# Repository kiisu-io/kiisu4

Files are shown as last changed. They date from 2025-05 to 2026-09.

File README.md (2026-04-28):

# Kiisu V4 docs, schematics and resources

## Kiisu V4b

[User Manual and Quick Start guide](https://github.com/kiisu-io/kiisu4/blob/main/kiisu%20v4b%20manual%20and%20quick%20start.pdf)

[Schematics](https://github.com/kiisu-io/kiisu4/blob/main/kiisu%20v4b%20schematics.pdf)

[STL file of board](https://github.com/kiisu-io/kiisu4/blob/main/kiisu%20v4b%20model.stl)

## Kiisu V4a

[User Manual for Kiisu v4a](https://github.com/kiisu-io/kiisu4/blob/main/previous/kiisu%20v4a%20manual.pdf)

[Schematics for Kiisu v4a](https://github.com/kiisu-io/kiisu4/blob/main/previous/kiisu%20v4a%20schematics.pdf)

## Check other resources:
- [Kiisu.io website](https://kiisu.io).
- [Buy Kiisu here](https://store.rainwalker.ee/products/kiisu-v4).
- [Our Discord Community](https://discord.gg/kiisu) can help with your questions.
- [Flipper Zero docs](https://docs.flipper.net/) to know more about Bluetooth, RFID, NFC, IR and other technologies and how to interact with it using compatible firmware on Kiisu board.

- [Aux MCU firmware to support Flipper Zero firmwares](https://github.com/kiisu-io/kiisu4-companion-fw).
- [Fork of Flipper Zero firmware for Kiisu](https://github.com/kiisu-io/kiisu-firmware).
- [Twoelw's GitHub](https://github.com/twoelw) with useful apps and firmware for Kiisu.

- [Cases and stuff for 3D printing on Printables](https://www.printables.com/@planmarks/collections/2364779).
- [Cases and stuff for 3D printing on Makerworld](https://makerworld.com/ru/collections/6517412-kiisu-devboard).

## See also

- [KIISU SMOL](https://github.com/kiisu-io/kiisu-smol) — hardware design files for our modular networking development board (currently on [Indiegogo](https://www.indiegogo.com/projects/rainwalker/kiisu-smol---networking-development-board)).

## License

Hardware design files (schematics, 3D models) are released under the [CERN Open Hardware Licence Version 2 — Strongly Reciprocal (CERN-OHL-S v2)](LICENSE).

Documentation, manuals, and this README are released under the [Creative Commons Attribution-ShareAlike 4.0 International (CC BY-SA 4.0)](LICENSE-DOCS).

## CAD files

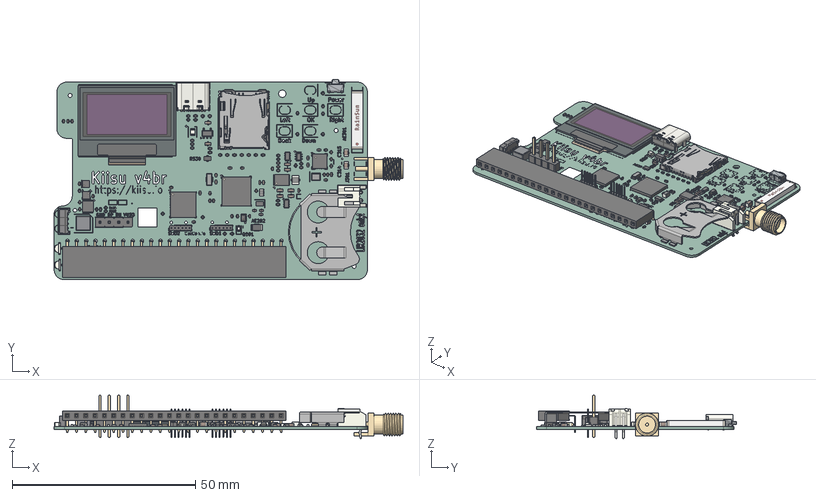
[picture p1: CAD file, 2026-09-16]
kiisu v4br model.step
95.3 x 54.8 x 11.9 mm
C_0402_1005Metric x 73
R_0402_1005Metric x 77
C_0603_1608Metric x 10
LED_0805_2012Metric
BatteryHolder_Keystone_3034_1x20mm
QFN-32-1EP_5x5mm_Pitch0.5mm
C_0805_2012Metric x 3
QFN-48-1EP_7x7mm_Pitch0.5mm
Crystal_SMD_2520-4Pin_2.5x2.0mm
User Library-0_96__OLED v7 v1
User Library-0_96__OLED v7 v002
User Library-0_96__OLED v7 v003
User Library-0_96__OLED v7 v004
D_SOD_523 x 4
SOT-323_SC-70
SOT-363_SC-70-6 x 5
MicroCrystal_CC8V_T1A
SOT-23-3
Bosch_LGA_8_3x3mm_P08mm_ClockwisePinNumbering
DFN-6-1EP_2x2mm_Pitch0.5mm
Scale (Solid)
R_1206_3216Metric
HeimdallW
PinHeader_1x06_P100mm_Vertical x 2
R_0805_2012Metric x 2
L_1008_2520Metric
LGA_12_2x2mm_P05mm
QFN-16-1EP_3x3mm_P0.5mm_EP1.7x1.7mm
DFN-14-1EP_3x4mm_Pitch0.5mm
L_0402_1005Metric x 2
LED_XINGLIGHT_1204_3210Metric_SideView x 2
USB_C_Receptacle_16P_TopMnt_Horizontal_GCT_USB4105-xx-A
L_0805_2012Metric x 3
PinHeader_1x04_P254mm_Vertical
SOT-583-8 x 2
F6C42762-D111-4FB0-B9BB-3CBC5E40C018
QFN_68_1EP_8x8mm_P04mm_EP52x52mm
Texas_RGP0020H_VQFN-20-1EP_4x4mm_P0.5mm_EP2.4x2.4mm
Crystal_SMD_3215-2Pin_3.2x1.5mm
SOT-23-5
microSD_HC_Hirose_DM3AT-SF-PEJM5
L_Abracon_ASPI-0425
LED_0603_1608Metric
JST_S2B_PH_K
D_SOD-323
Crystal_SMD_3225-4Pin_3.2x2.5mm
Filter_Mini-Circuits_FV1206-5
SMA_Samtec_SMA-J-P-H-ST-EM1_EdgeMount
PinSocket_1x24_P2.54mm_Horizontal
kii89D0_silkscreen x 2
kii89D0_PCB

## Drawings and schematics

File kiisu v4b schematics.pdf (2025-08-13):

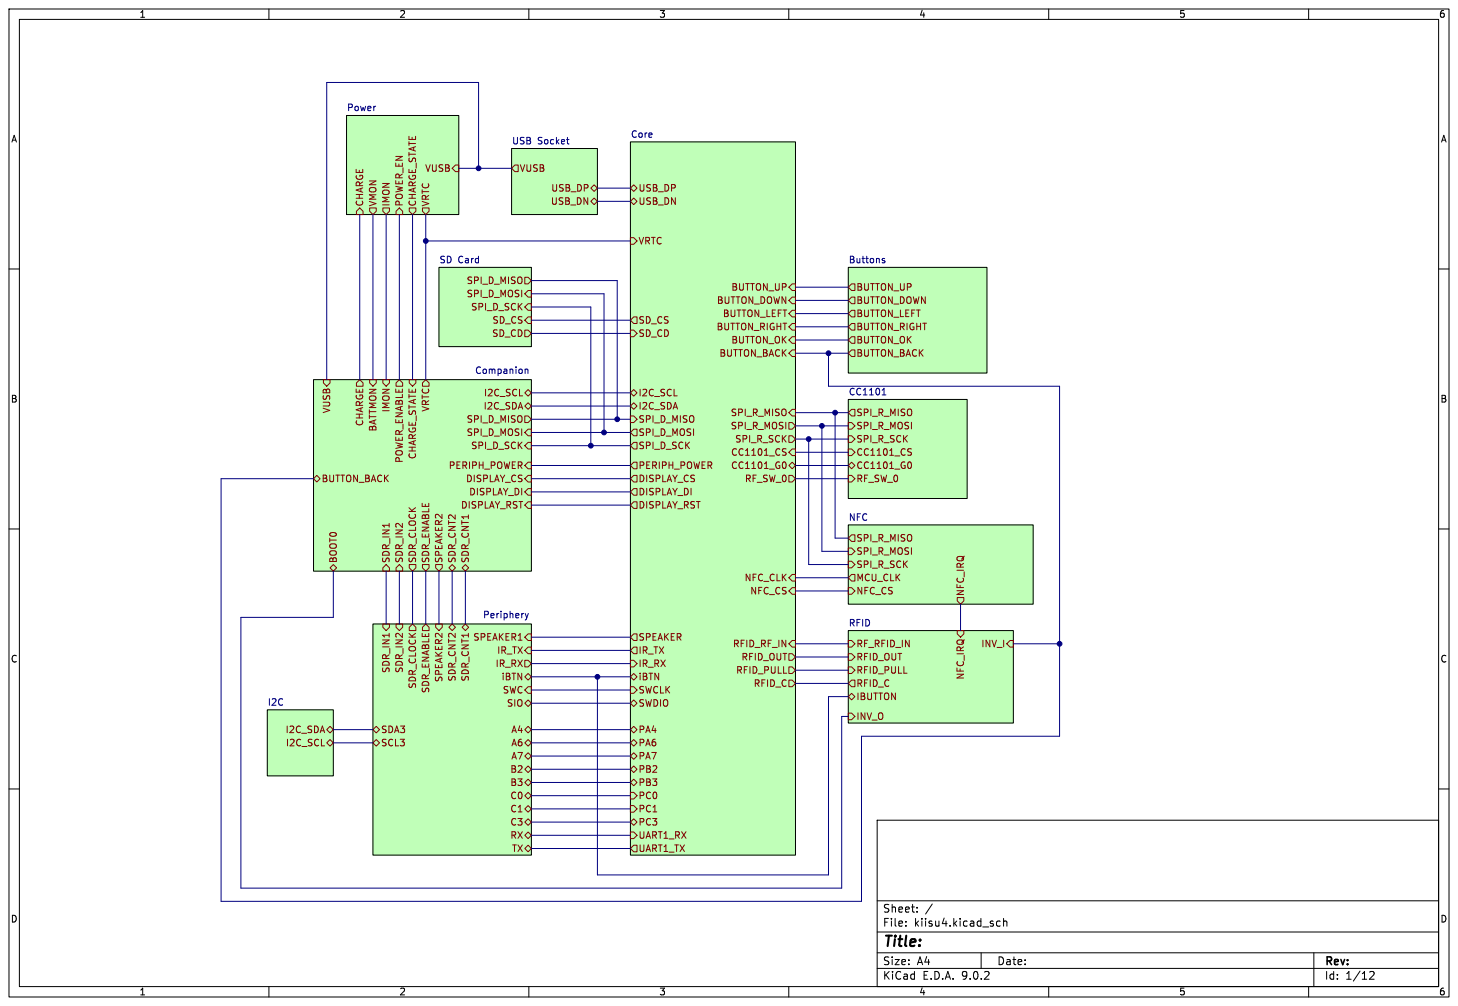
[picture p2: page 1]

VUSB CHARGE VMON IMON POWER_EN CHARGE_STATE VRTC

Id: 1/12 Title: File: kiisu4.kicad_sch Sheet: /

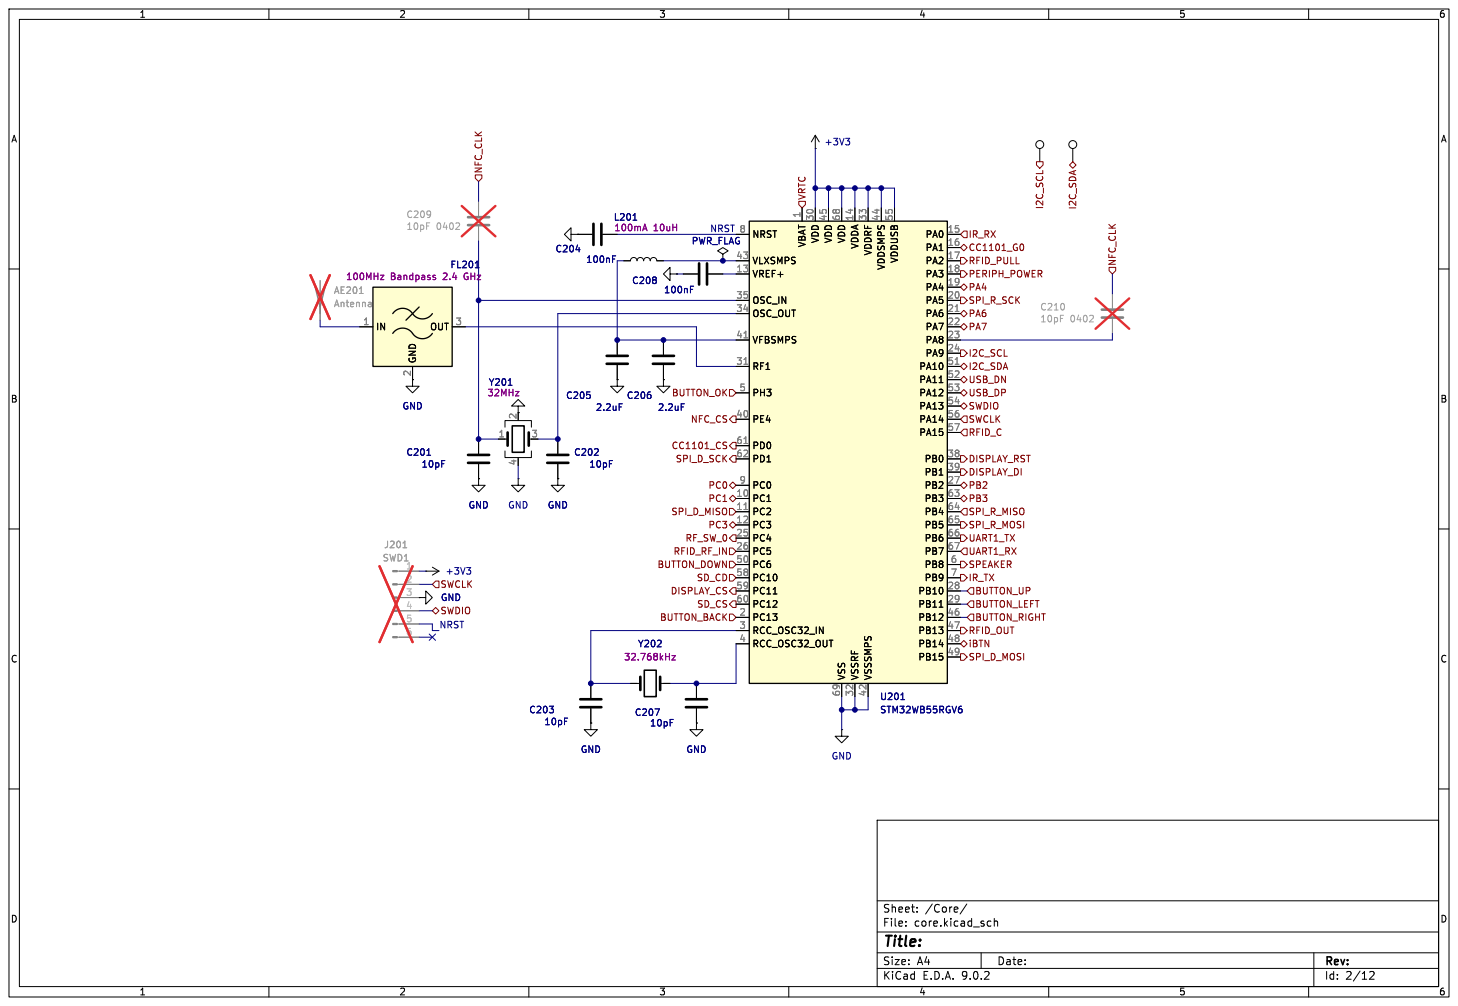
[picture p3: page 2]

Id: 2/12 Title: File: core.kicad_sch Sheet: /Core/ C201

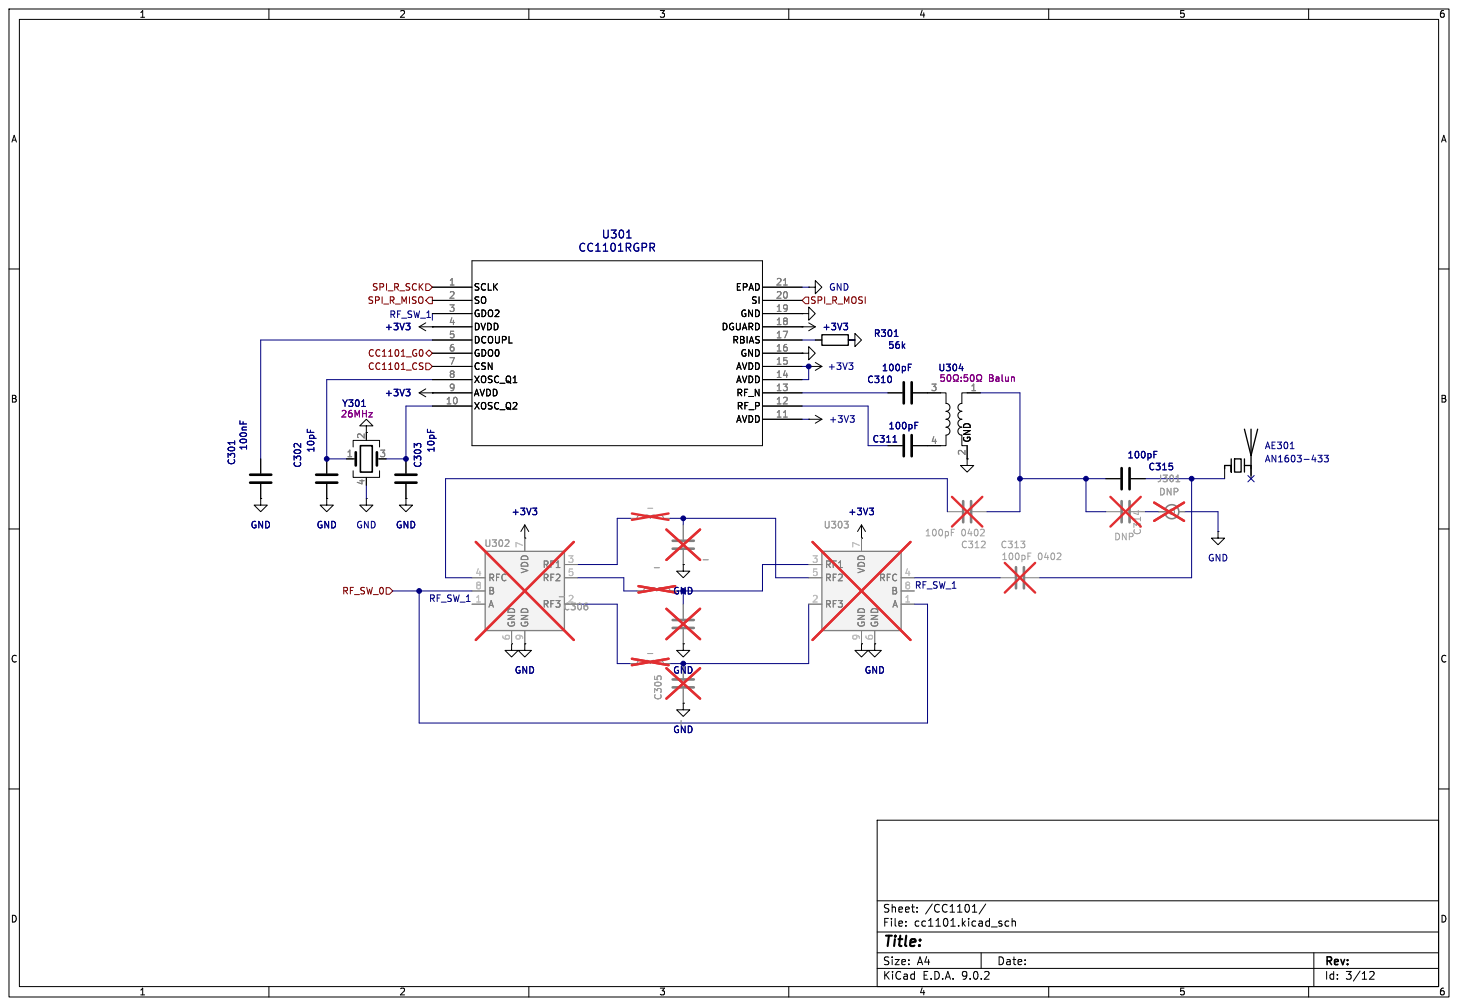
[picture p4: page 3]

Id: 3/12 Title: File: cc1101.kicad_sch Sheet: /CC1101/

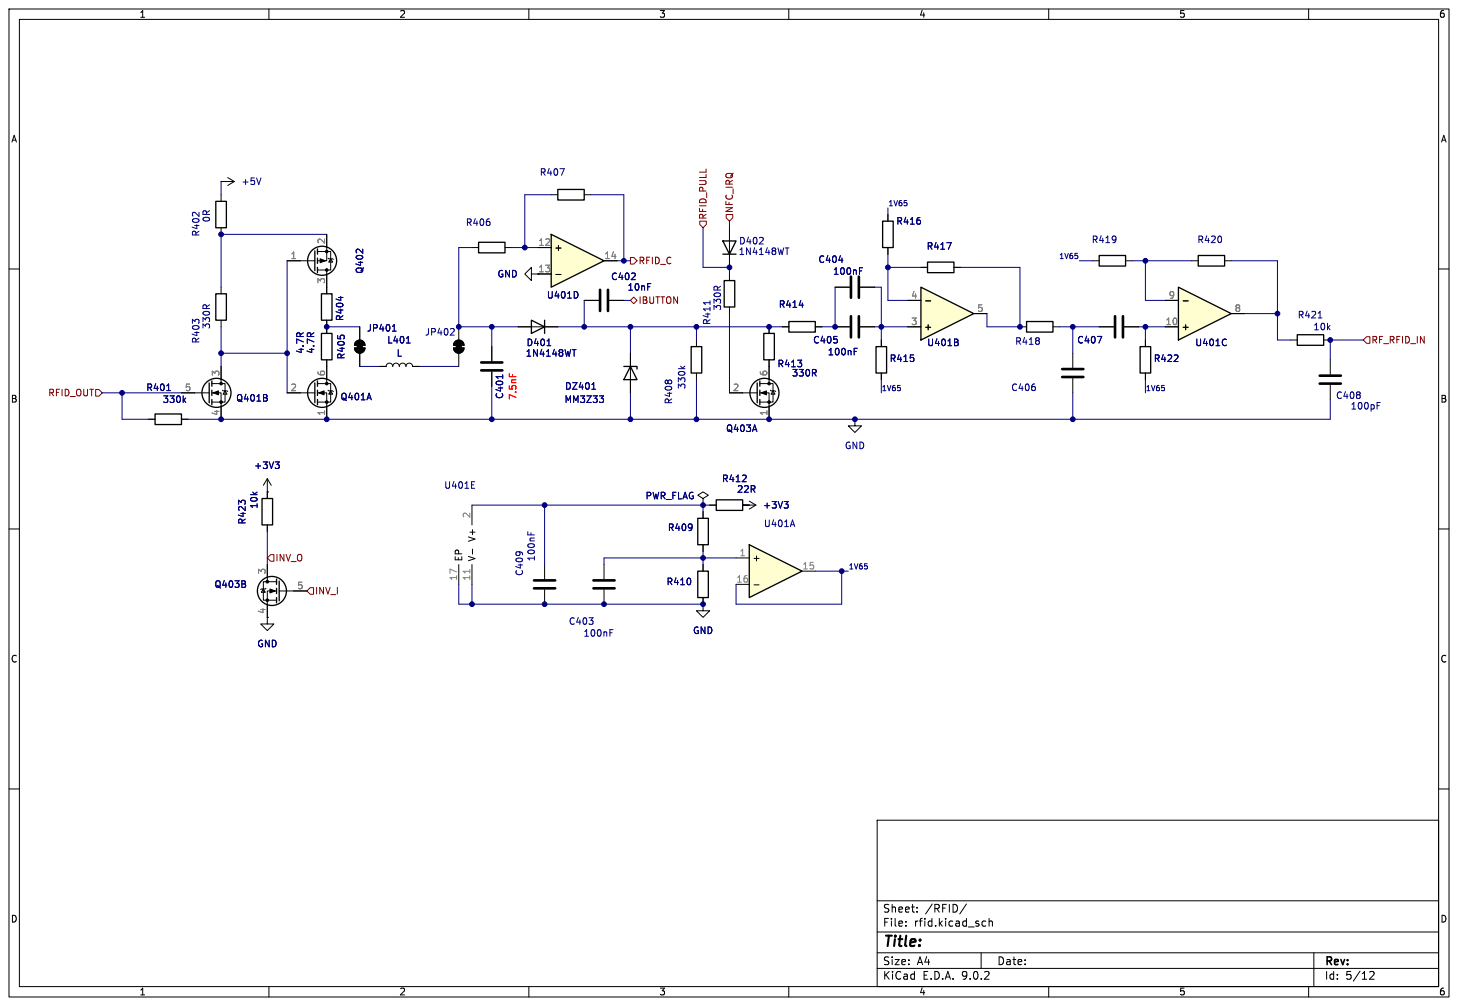
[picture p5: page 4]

Id: 5/12 Title: File: rfid.kicad_sch Sheet: /RFID/

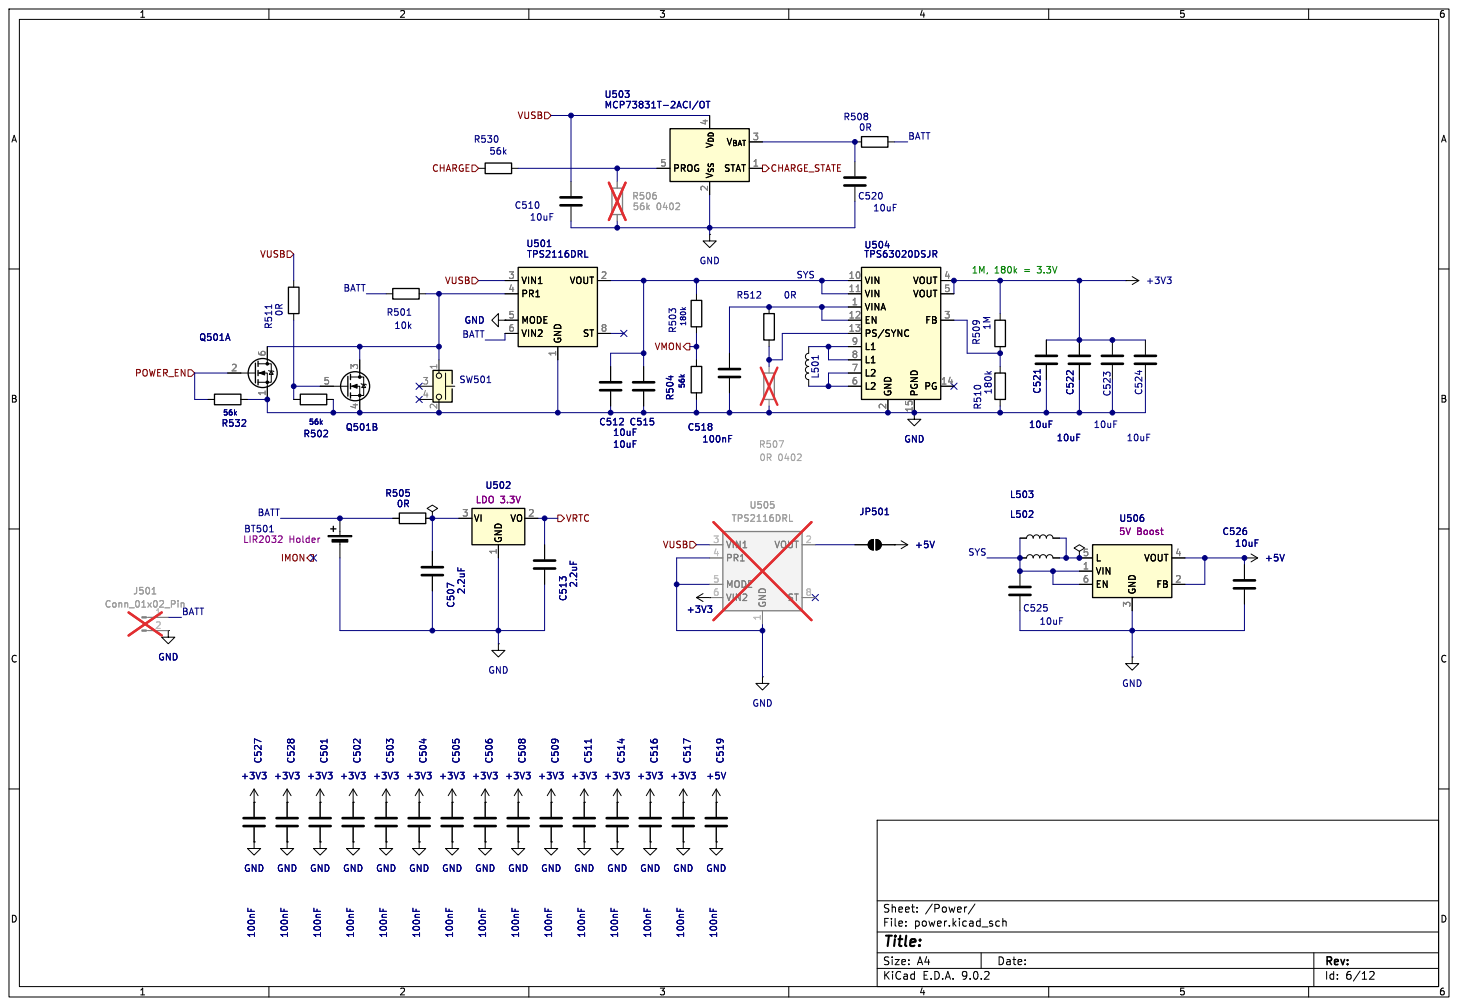
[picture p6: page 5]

1 VOUT 2 ST 8 +3V3 U501 TPS2116DRL VIN1 3 PR1 4 MODE 5 VIN2 6 GND

2 PGND 15 VOUT 4 VOUT 5 FB 3 PG 14 U504 TPS63020DSJR

2 PGND 15 VOUT 4 VOUT 5 FB 3 PG 14 U506

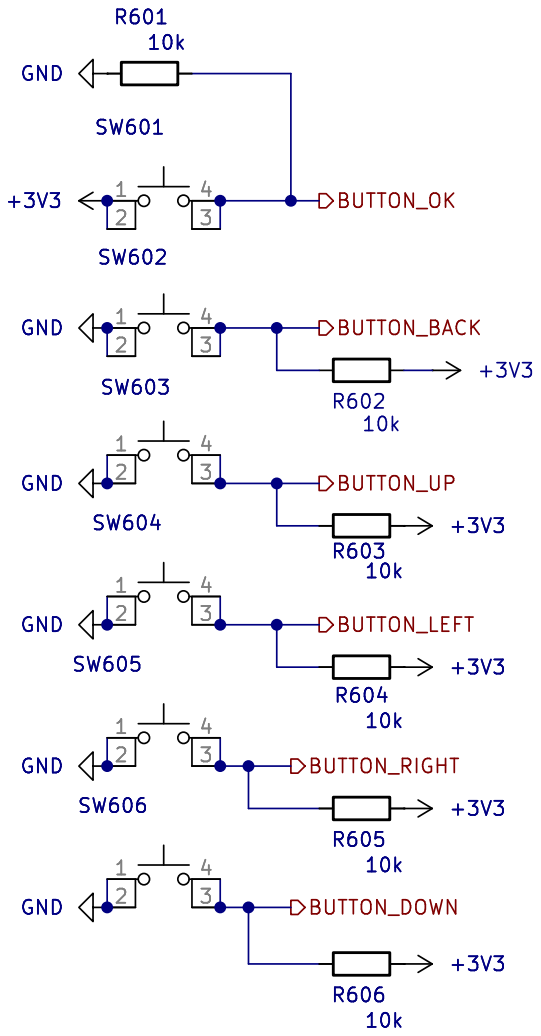
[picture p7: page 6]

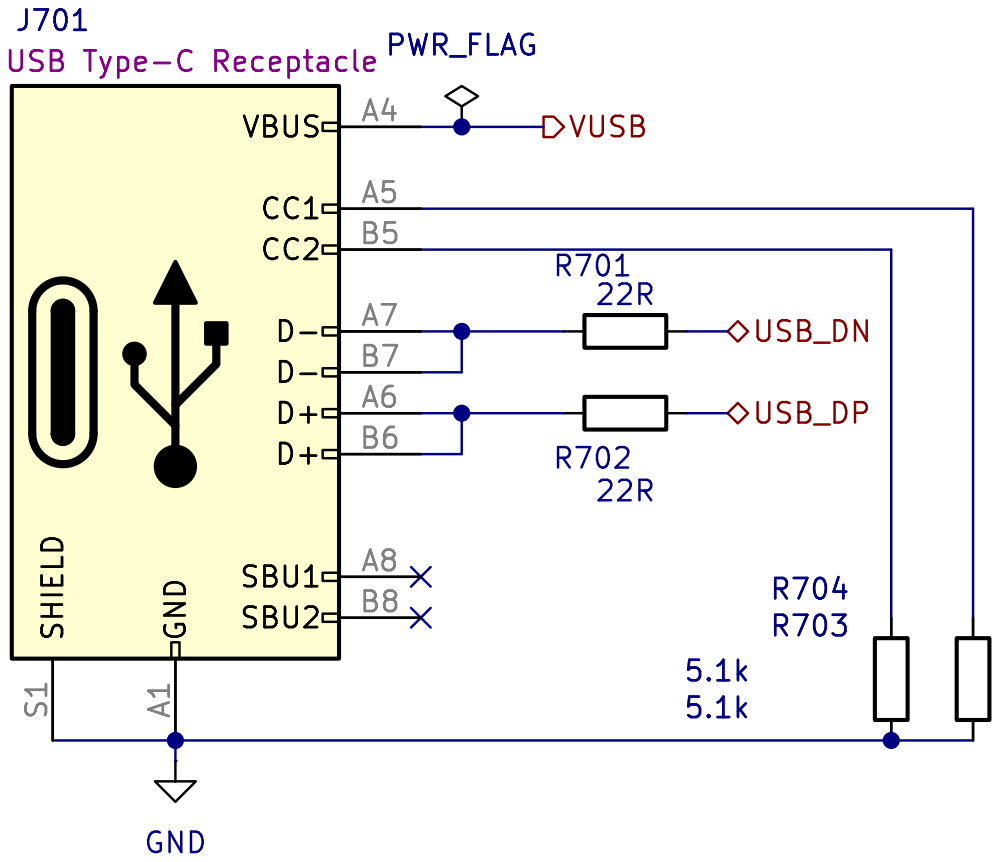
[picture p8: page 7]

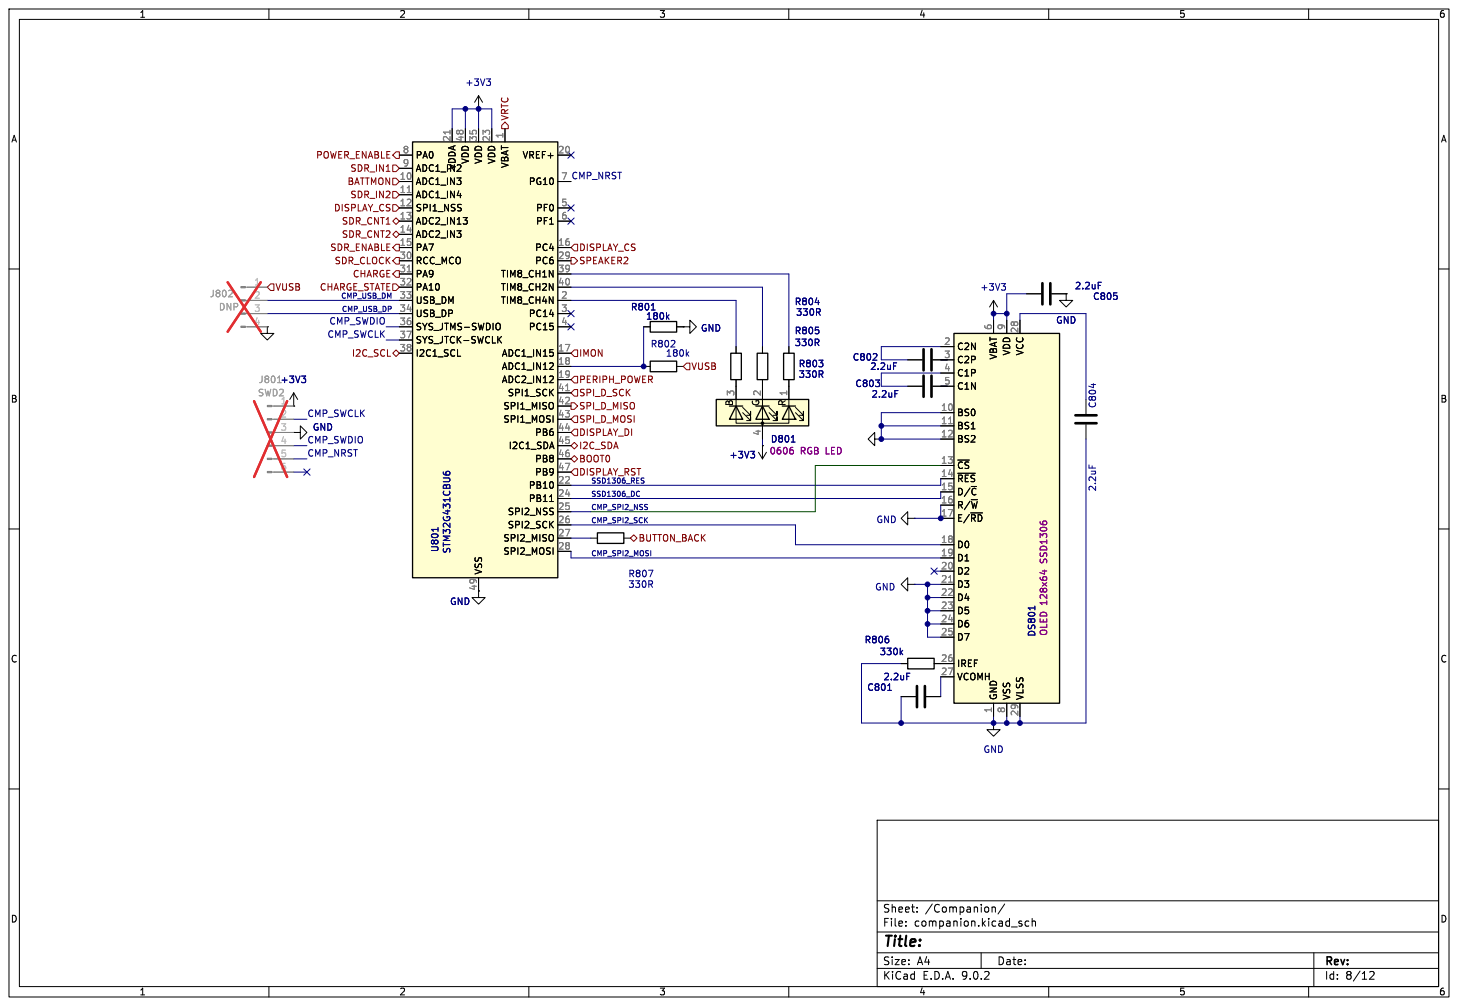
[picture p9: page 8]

Id: 8/12 Title: File: companion.kicad_sch Sheet: /Companion/

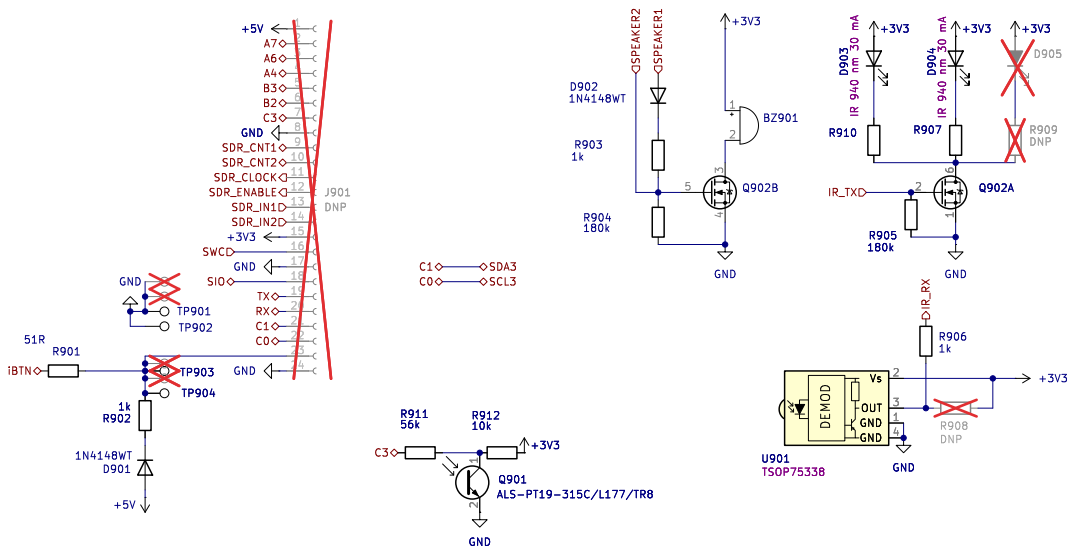
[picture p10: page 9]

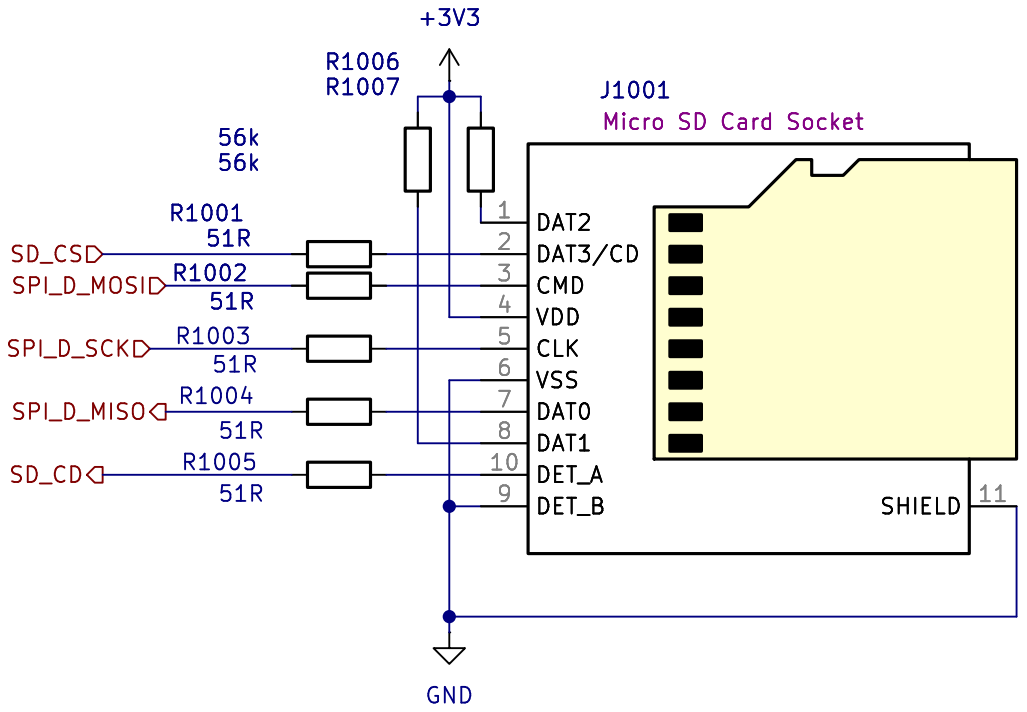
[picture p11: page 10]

J1001 Micro SD Card Socket SPI_D_SCK

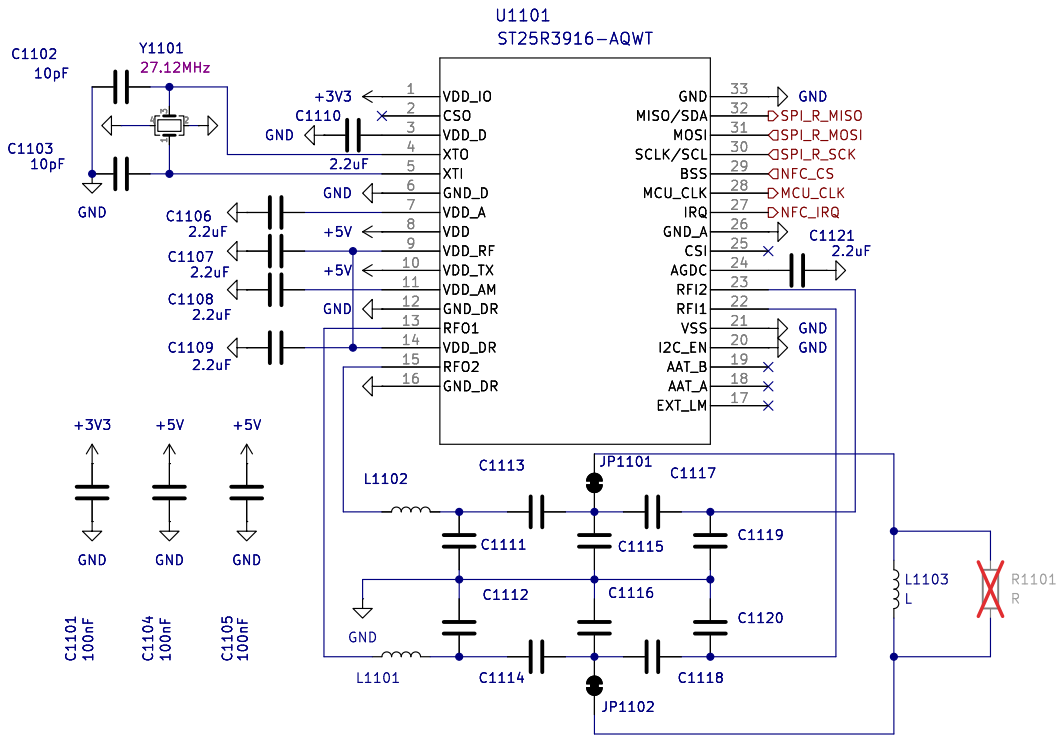
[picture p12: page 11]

Id: 11/12 Title: File: nfc.kicad_sch Sheet: /NFC/

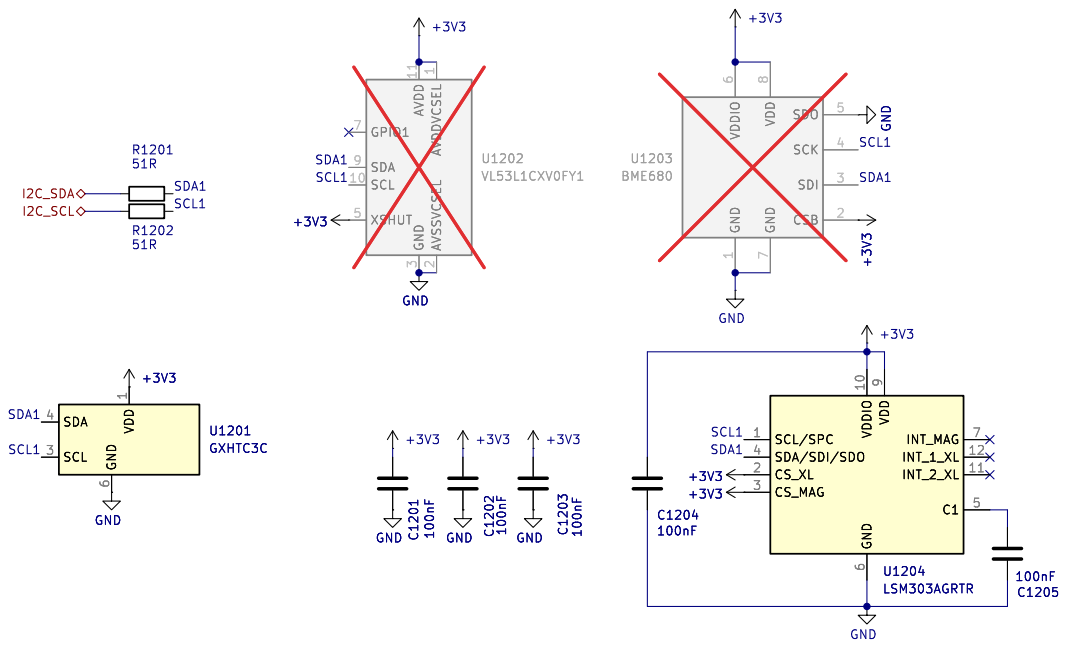
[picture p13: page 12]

1 U1202 VL53L1CXV0FY1 GPIO1 7 SDA 9 SCL 10 XSHUT 5 AVDD 11 GND

7 SDO 5 SCK 4 SDI 3 CSB 2 U1203 BME680 +3V3 GND

7 SDO 5 SCK 4 SDI 3 CSB 2 +3V3

2 GND C1203 100nF GND GND C1202 100nF GND C1201 100nF

Id: 12/12 Title: File: I2C.kicad_sch Sheet: /I2C/

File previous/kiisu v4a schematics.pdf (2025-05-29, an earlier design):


USB Socket VUSB CHARGE VMON IMON POWER_EN CHARGE_STATE VRTC

Id: 1/12 Title: File: kiisu4.kicad_sch Sheet: /


Id: 2/12 Title: File: core.kicad_sch Sheet: /Core/


Id: 3/12 Title: File: cc1101.kicad_sch Sheet: /CC1101/


Id: 5/12 Title: File: rfid.kicad_sch Sheet: /RFID/


2 PGND 15 VOUT 4 VOUT 5 FB 3 PG 14 U504 TPS63020DSJR

VIN 10 VIN 11 VINA 1 EN 12 PS/SYNC 13

2 PGND 15 VOUT 4 VOUT 5 FB 3 PG 14

1 VOUT 2 NC 7 ST 8 GND

1 VOUT 2 NC 7 ST 8 U505 VI TPS2116DRL 3 GND

Id: 6/12 Title: File: power.kicad_sch Sheet: /Power/




Id: 8/12 Title: File: companion.kicad_sch Sheet: /Companion/



J1001 Micro SD Card Socket SPI_D_SCK


Id: 11/12 Title: File: nfc.kicad_sch Sheet: /NFC/ C1114 GND


7 SDO 5 SCK 4 SDI 3 CSB 2 U1203 BME680 +3V3GND +3V3 C1202 100nF 0402 GPIO1 7 SDA 9 SCL 10 XSHUT 5 AVDD 11 GND

7 SDO 5 SCK 4 SDI 3 CSB 2 +3V3 GND

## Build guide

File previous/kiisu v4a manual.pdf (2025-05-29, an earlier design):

1

# Kiisu Development Board v4a

# User Manual

Rainwalker OU, 2025
Document version 1.0 from 1.04.2025 Find the latest version here: https://github.com/kiisu-io/kiisu4

2

## Cautions and warnings

1. This is a development board intended for experienced users; it is not a consumer product.
2. The development board can contain small and/or dangerous parts and must be kept away from children.
3. Use only LIR2032 batteries, never use CR2032 or another types on coin cell batteries.
4. Development board can emit radio frequency signals. Users are responsible for complying with local EMI regulations.

## Contents

6. Updating and debugging Main and Aux MCU with ST-Link or

## 1. Board overview

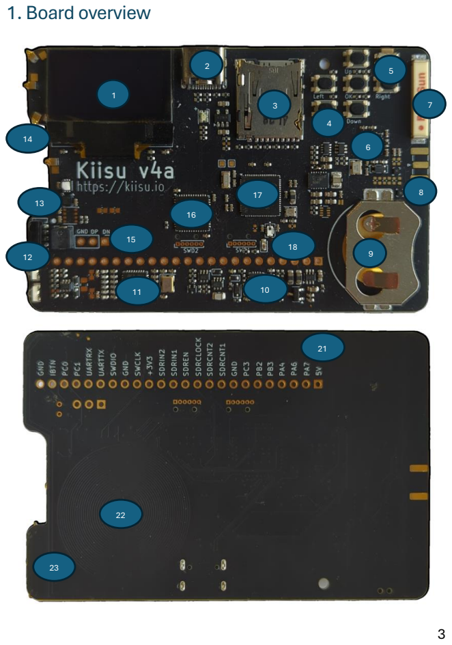
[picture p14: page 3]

4

1. OLED 128x64 screen, SSD1306 compatible in SPI mode.
2. USB Type C connected to Main MCU (17), supports charging of LIR2032 battery (9).
3. microSD Card slot.
4. Control buttons.
5. Power On button.
6. SubGhz transceiver CC1101.
7. Internal 433 MHz antenna for CC1101.
8. Place for SMA connector for external antenna.
9. LIR2032 battery connector. Do not use another type of coin cell batteries!
10. RFID reader and emulator with built-in antenna (23).
11. NFC reader and emulator ST25R3916 with built-in antenna (23).
12. Infrared receiver and transmitter.
13.Digital accelerometer and compass LSM303AGR. Temperature and humidity sensor GXHTC3C.
Gas sensor measuring relative humidity, barometric pressure, ambient temperature and gas (VOC) BME680 can be installed by user.
Digital ranger VL53xxx can be installed by user.
14. iButton memory reader and emulator pins
15.USB header connected to Aux MCU (16).
16. Aux MCU STM32G431CBU6 up to 170 MHz 17.Main MCU STM32WB55RGV6 up to 80 MHz
18. Ambient light sensor
21. GPIO pins.

5

## 2. Schematics and resources

Board schematics, latest version of this manual can be found here: https://github.com/kiisu-io/kiisu4
Aux MCU demonstration firmware can be found here: https://github.com/kiisu-io/kiisu4-companion-fw
This firmware allows to run and develop any Flipper Zero firmware with some limitations. (Note: Rainwalker OU and Kiisu board are NOT affiliated with Flipper Zero Devices Inc or team)
Fork of official Flipper Zero Firmware can be found here: https://github.com/kiisu-io/kiisu-firmware
This fork can also be run on Flipper Zero.

## 3. Limitations of compatibility

Despite this development, the board can run almost any firmware for the Flipper Zero device, there are some limitations:
1. The board doesn’t contain Flipper Zero secret keys, so official firmware may not support some SubGhz protocols and U2F.
2. The performance of board antennas can differ.
3. Some parts of the schematic are different, so features like battery status depend on Aux MCU firmware.
4. Once again, this is development board, not final end user device.

6

## 4. Powering on

Board can be powered from USB (2), from Li-Ion battery LIR2032 (9) and external Li-Ion battery.
In the case of USB, the board will turn on automatically and will remain powered until there is USB voltage.
In case of LIR2032, users should press Power On button (5). Board power than controlled by Aux MCU.

## 5. Updating firmware for Main MCU over USB

1. Disconnect USB and remove battery.
2. Press and hold OK Button (5).
3. Connect USB Type C (2).
4. Main MCU will enter in DFU mode and can be updated by STM32CubeProgrammer, qFlipper and other software.

## 6. Updating firmware for Aux MCU over USB

1. Disconnect all USB and remove battery.
2. Press and hold Back Button (5).
3. Connect USB Type C (2).
4. Connect USB cable to Aux USB pins (15). You need to prepare this cable by yourself.
5. Aux MCU will enter in DFU mode and can be updated by STM32CubeProgrammer and other software.

7

## 7. Updating and debugging Main and Aux MCU with ST-Link or other debugging tools

You can use ST-Link or other debugging tools, connecting them to SWD1 header (for main MCU) or SWD2 header (for aux MCU). Header is 1x6 row with 1 mm step. Here is the pinout:
1 – Voltage reference
for debugging tool
2 – SWD Clock
3 – Ground
4 – SWD IO
5 – Reset
6 – Not used

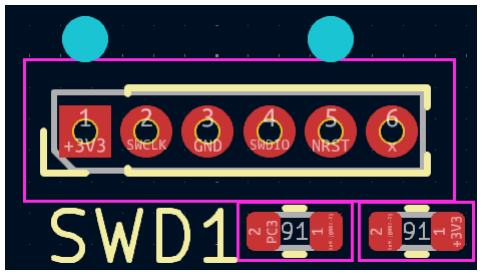
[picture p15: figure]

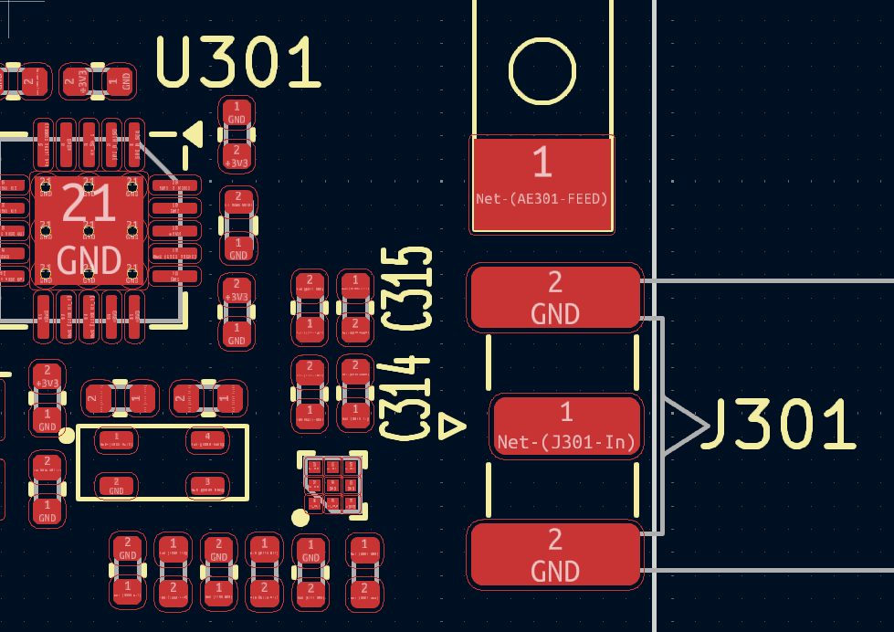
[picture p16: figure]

8

## 8. Connecting external antenna to CC1101 transceiver

1. Remove C315.
2. Solder jumper to C314.
3. Solder SMA edge connector to J301.

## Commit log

2025-05-29 Schematics v4a.
2025-08-13 v4b schematics and 3d models
2026-01-02 Added info about NFC antenna tuning.
2026-02-11 kiisumini v1a schematics and models
2026-02-11 kiisumini v1a expansion board sample project and footprints
    [km-2032.kicad_pcb, km-2032.kicad_sch]
2026-04-28 Migrate KIISU SMOL files to dedicated kiisu-smol repo, add licenses
    - Move kiisumini v1a hardware files (formerly the legacy name for KIISU SMOL)
    to https://github.com/kiisu-io/kiisu-smol
    - Add LICENSE: CERN-OHL-S v2 (hardware design files)
    - Add LICENSE-DOCS: CC-BY-SA 4.0 (documentation, manuals, README)
    - README: add "See also" pointer to kiisu-smol and a License section
    [km-2032.kicad_pcb, km-2032.kicad_sch]
2026-09-16 V4BR models update
    [kiisu v4br model.step]
